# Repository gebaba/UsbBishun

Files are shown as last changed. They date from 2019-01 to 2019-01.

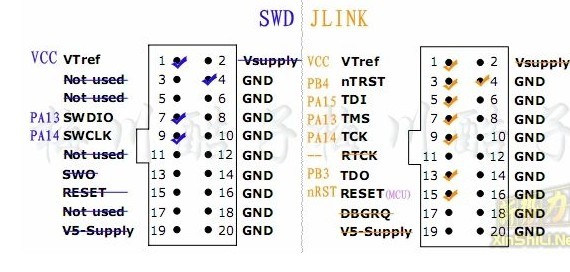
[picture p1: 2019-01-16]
Documents/DEBUG.jpg

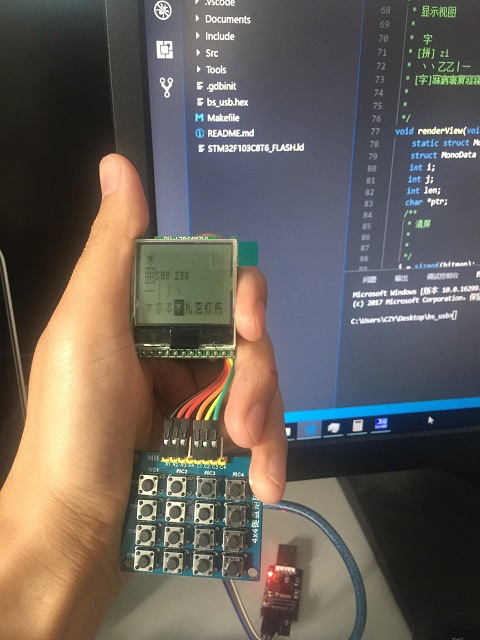
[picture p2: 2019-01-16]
20181016140855.jpg

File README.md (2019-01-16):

# 带笔画输入法的键盘

1 横/提<br />
2 竖/竖钩<br />
3 撇<br />
4 捺/点<br />
5 折<br />
6 回退/清除<br />
7 确定/模式<br />
8 上翻/放大<br />
9 下翻/缩小<br />



# 第一版问题

W26Q16 存储器和 STM32F103C8T6 的 SPI1 接口错误 PA6/PA7 颠倒<br />
复位按键封装过小<br />
USB 口 500mA 电阻封装过小<br />
按键和 LCD 的接口根据布线进行调整<br />
屏幕灯的封装过小<br />
32769 晶震处过孔<br />

外壳液晶屏位置调整<br />
外壳腔体高度过低需要留有一定余量<br />

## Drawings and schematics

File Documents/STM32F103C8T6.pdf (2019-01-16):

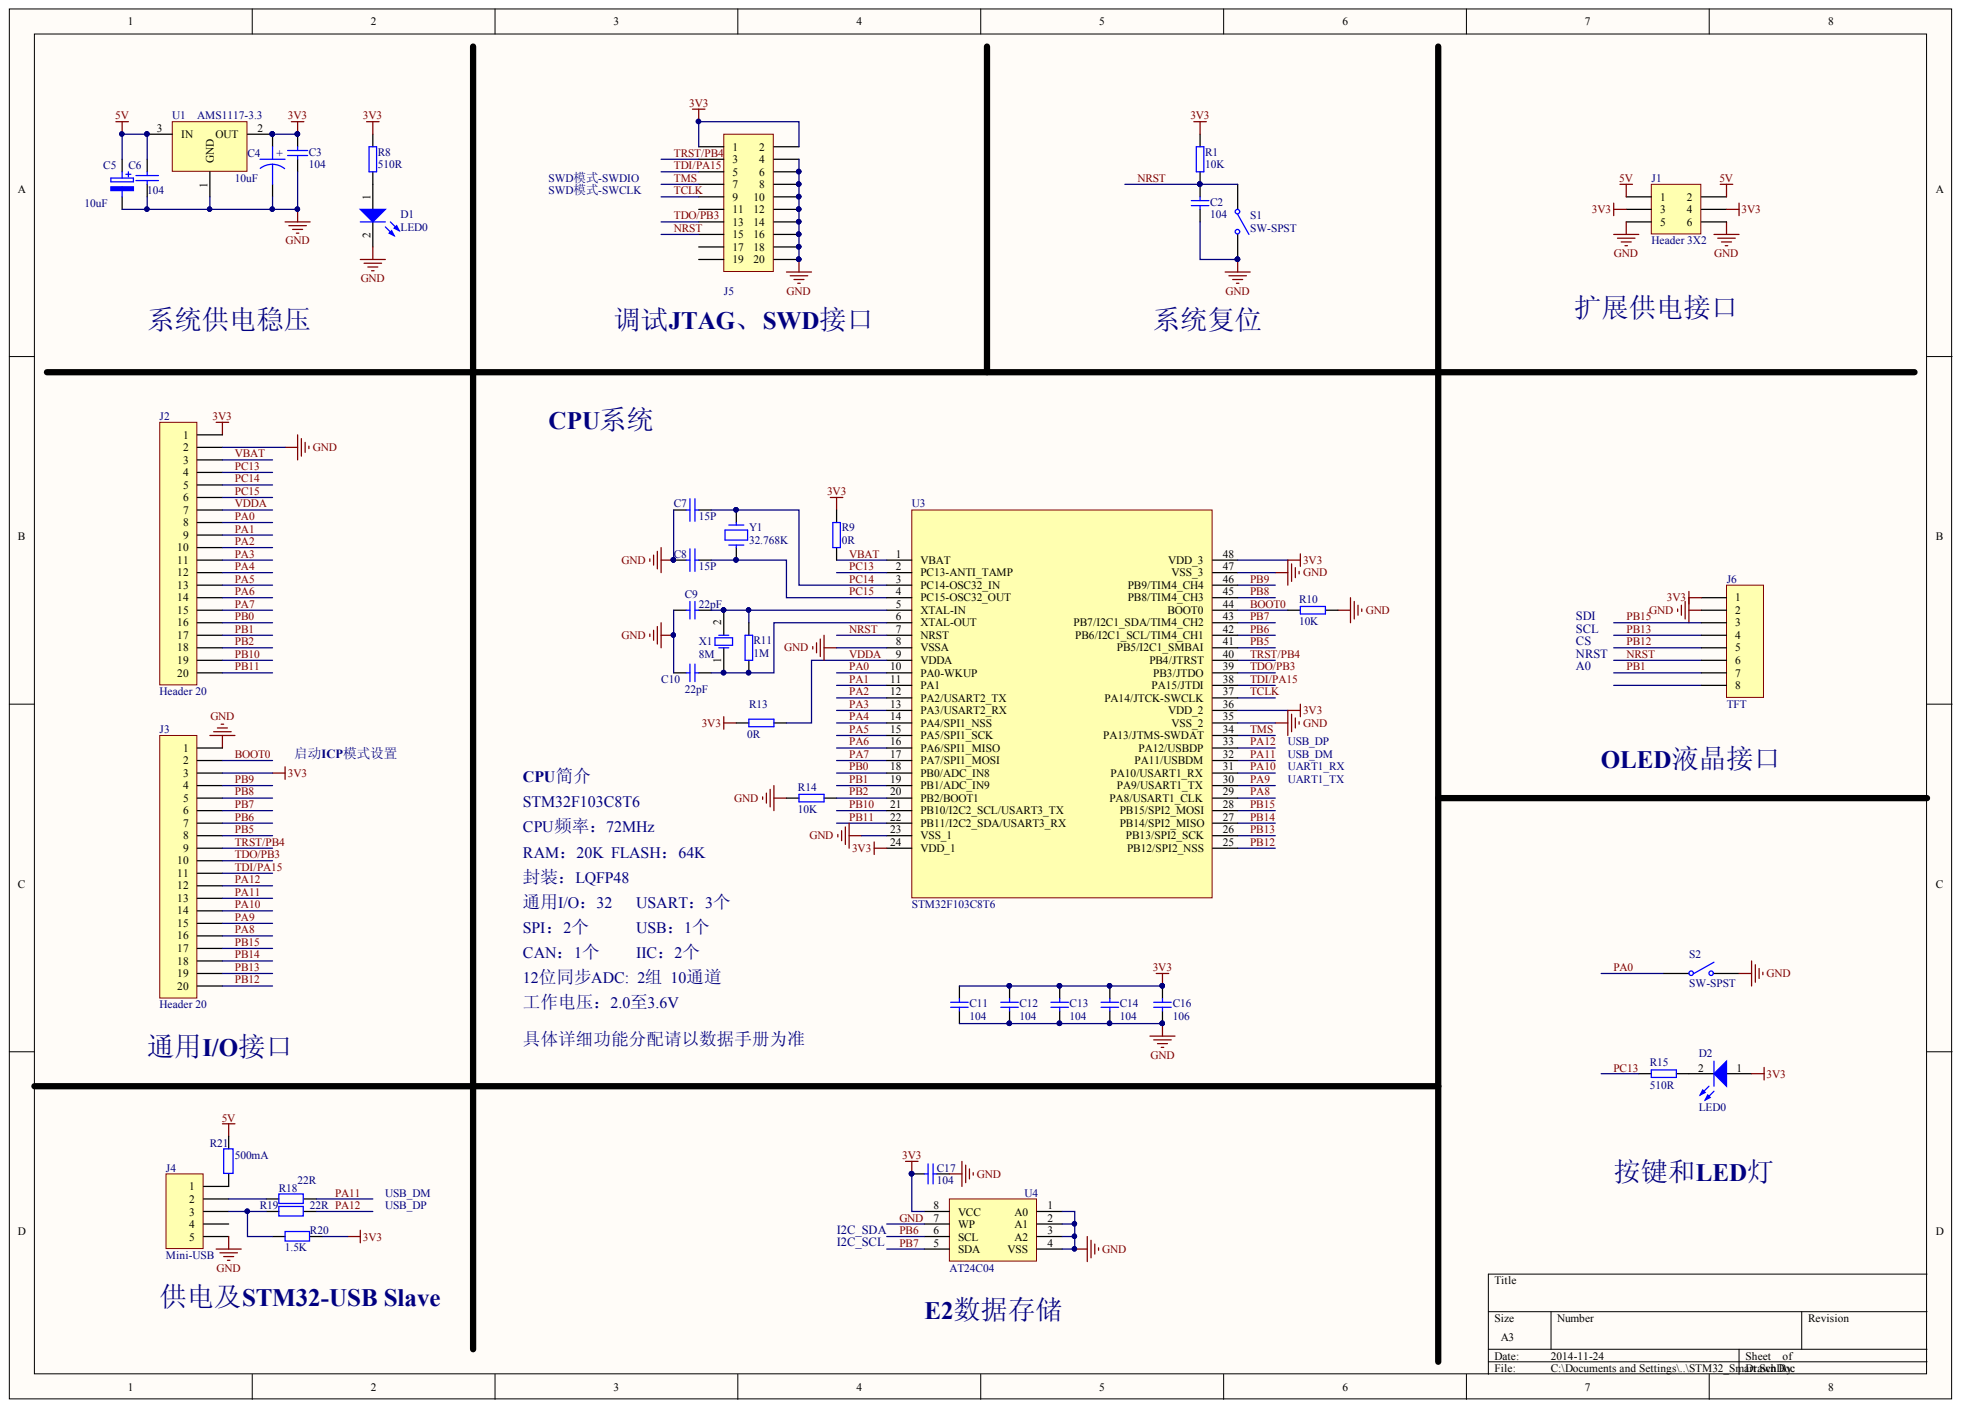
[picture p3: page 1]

tr.SchD awn Bocy:

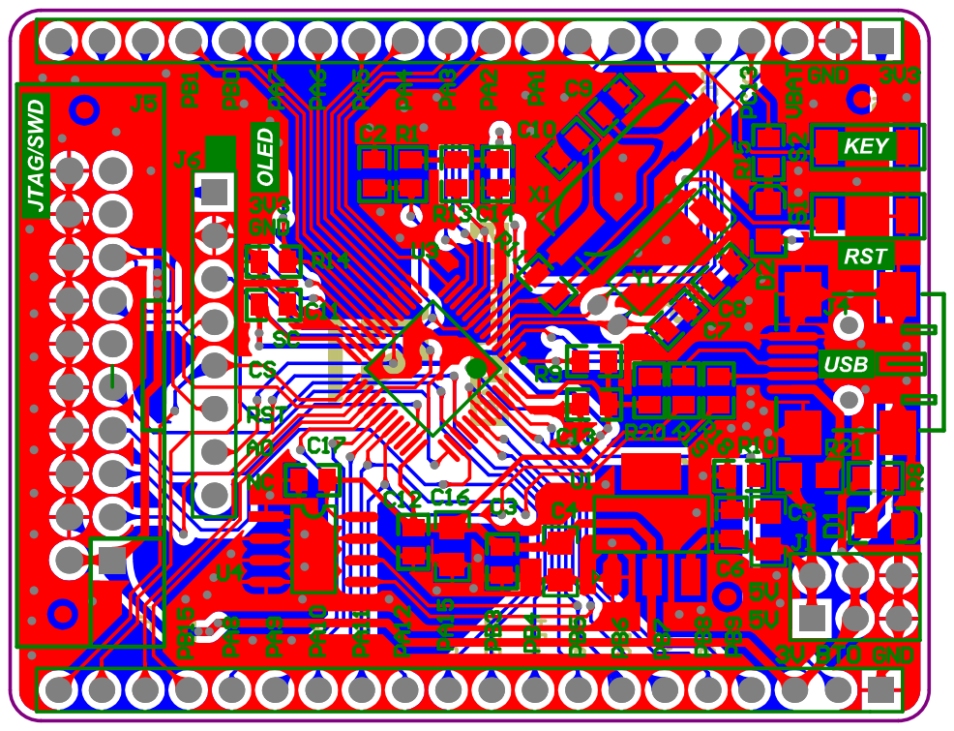
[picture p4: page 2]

Comment | Description | Designator | Footprint | LibRef | Quantity
104 | Capacitor | C2, C3, C6, C11, C12, C13, C14, C17 | RC0603 | CAP1, Cap, CAP, CAP1, CAP1, CAP1, CAP1, Cap | 8
10uF | Capacitor, [NoValue] | C4, C5 | RC0805 | CAPACITOR POL, ELECTRO2 | 2
15P | | C7, C8 | RC0603 | CAP | 2
22pF | Capacitor | C9, C10 | RC0603 | CAP1 | 2
106 | Capacitor | C16 | RC0805 | CAP1 | 1
LED0 | Typical INFRARED GaAs LED | D1, D2 | LED0805 | LED0 | 2
Header 3X2 | Header, 3-Pin, Dual row | J1 | IDE3X2-2.54 | Header 3X2 | 1
Header 20 | Header, 20-Pin | J2, J3 | HDR1X20 | Header 20 | 2
Mini-USB | Header, 5-Pin | J4 | mini_USB | Header 5 | 1
| Header, 10-Pin, Dual row, Right Angle | J5 | JTAG20P | Header 10X2H | 1
TFT | Header, 8-Pin | J6 | HDR1X8 | Header 8 | 1
10K | | R1, R10, R14 | RC0603 | R | 3
510R | | R8, R15 | RC0603 | R | 2
0R | | R9, R13 | RC0603 | R | 2
1M | | R11 | RC0603 | R | 1
22R | Resistor | R18, R19 | RC0603 | Res2 | 2
1.5K | Resistor | R20 | RC0603 | Res2 | 1
500mA | Resistor | R21 | RC0805 | Res2 | 1
SW-SPST | Single-Pole, Single-Throw Switch | S1, S2 | SMT-KEY | SW-SPST | 2
AMS1117-3.3 | | U1 | SOT223 | LT1085CM-3.3 | 1
STM32F103C8T6 | | U3 | LQFP48 | STM32F103C8T6 | 1
AT24C04 | | U4 | SOIC-8P | EPROM | 1
8M | Crystal Oscillator | X1 | SMD49S | XTAL_SMD | 1
32.768K | 晶振 | Y1 | JZ32768 | CRYSTAL | 1

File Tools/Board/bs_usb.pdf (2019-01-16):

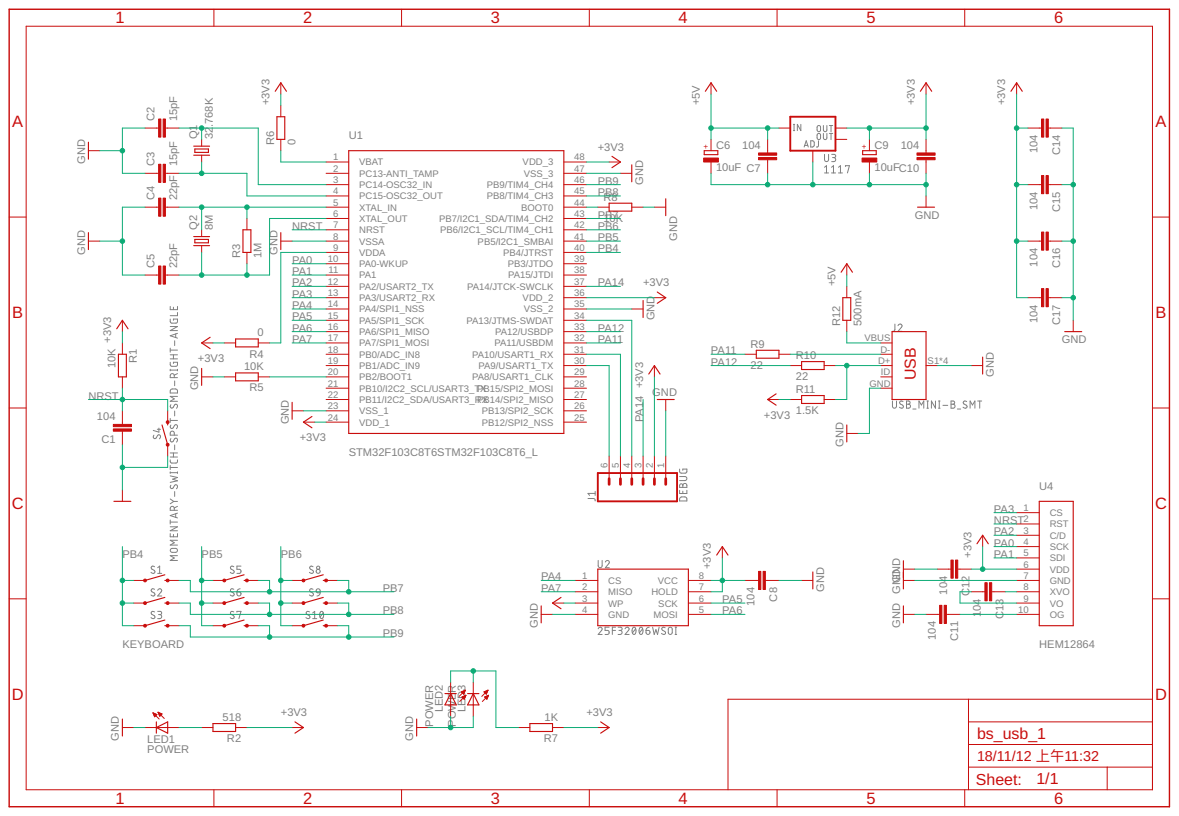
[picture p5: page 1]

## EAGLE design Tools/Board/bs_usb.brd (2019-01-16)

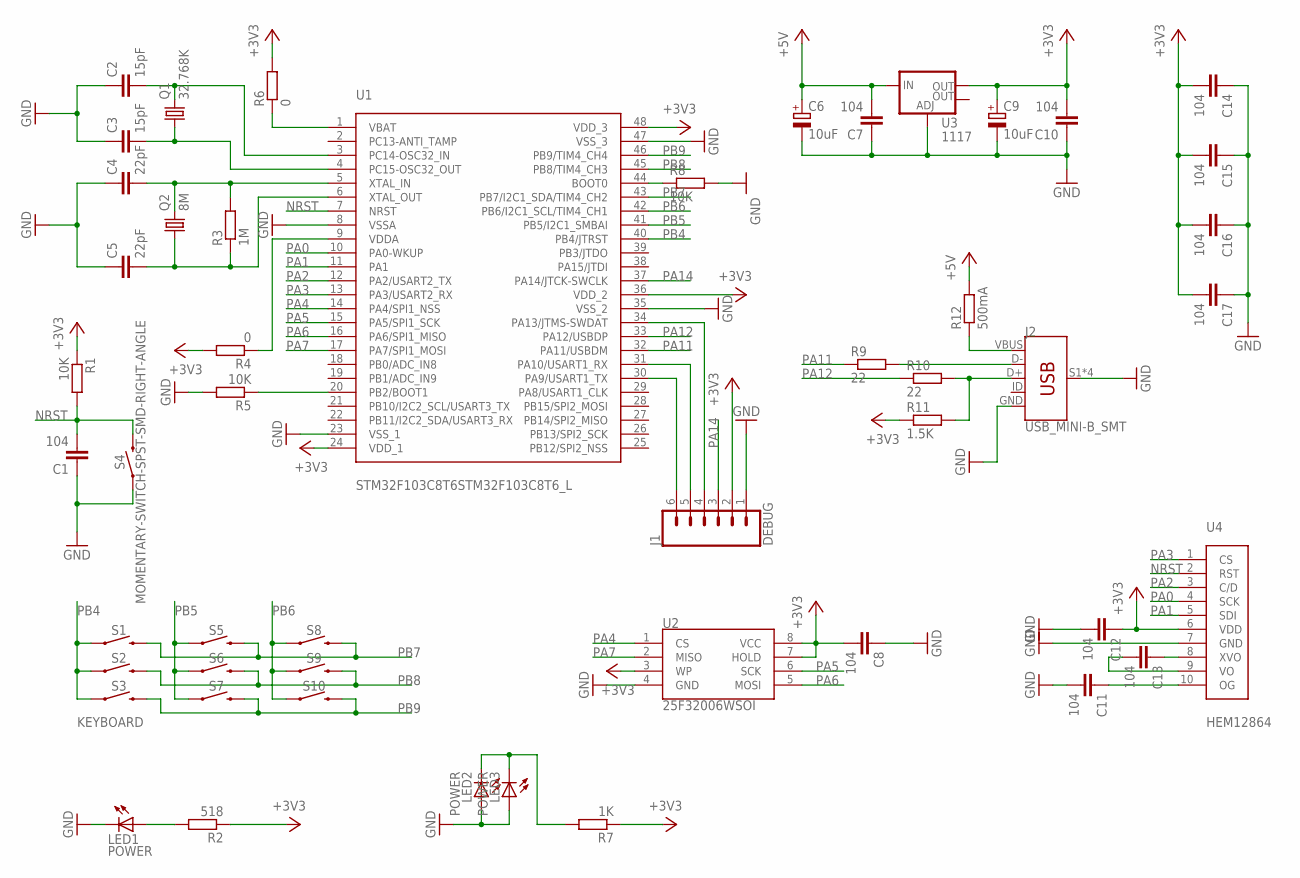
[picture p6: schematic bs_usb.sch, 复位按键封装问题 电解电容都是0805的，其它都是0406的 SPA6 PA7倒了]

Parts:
C1, C7, C8, C10, C11, C12, C13, C14, C15, C16, C17: 104; C0603
C2, C3: 15pF; C0603
C4, C5: 22pF; C0603
C6, C9: 10uF; A/3216-18R
J1: DEBUG; 1X06_NO_SILK
J2: USB_MINI-B_SMT; USB-MINIB
LED1, LED2, LED3: POWER; CHIP-LED0805
Q1: 32.768K; TC26H
Q2: 8M; SM49
R1, R5, R8: 10K; R0603
R2: 518; R0603
R3: 1M; R0603
R4, R6: 0; R0603
R7: 1K; R0603
R9, R10: 22; R0603
R11: 1.5K; R0603
R12: 500mA; R0603
S1, S2, S3, S5, S6, S7, S8, S9, S10: MOMENTARY-SWITCH-SPST-PTH-6.0MM; TACTILE_SWITCH_PTH_6.0MM
S4: MOMENTARY-SWITCH-SPST-SMD-RIGHT-ANGLE; TACTILE_SWITCH_SMD_RIGHT_ANGLE
U1: STM32F103C8T6STM32F103C8T6_L; TQFP48_7X7
U2: 25F32006WSOI; SO08-EIAJ
U3: 1117; SOT223
U4: HEM12864

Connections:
+3V3: C8.2, C9.+, C10.2, C12.1, C14.2, C15.2, C16.2, C17.2, J1.2, R1.1, R2.1, R4.2, R6.2, R7.1, R11.1, U1.24 (VDD_1), U1.36 (VDD_2), U1.48 (VDD_3), U2.3 (WP), U2.7 (HOLD), U2.8 (VCC), U3.2 (OUT), U4.6 (VDD)
+5V: C6.+, C7.2, R12.2, U3.3 (IN)
GND: C1.1, C2.1, C3.1, C4.1, C5.1, C6.-, C7.1, C8.1, C9.-, C10.1, C11.2, C12.2, C14.1, C15.1, C16.1, C17.1, J1.1, J2.GND, J2.S1 (SHIELD), J2.S2 (SHIELD), J2.S3 (SHIELD), J2.S4 (SHIELD), LED1.C, LED2.A, LED3.A, R5.2, R8.2, S4.1, U1.8 (VSSA), U1.23 (VSS_1), U1.35 (VSS_2), U1.47 (VSS_3), U2.4 (GND), U3.1 (ADJ), U4.7 (GND)
unnamed: R8.1, U1.44 (BOOT0)
unnamed: R6.1, U1.1 (VBAT)
unnamed: R5.1, U1.20 (PB2/BOOT1)
unnamed: R4.1, U1.9 (VDDA)
unnamed: C4.2, Q2.2, R3.2, U1.5 (XTAL_IN)
unnamed: C2.2, Q1.2, U1.3 (PC14-OSC32_IN)
unnamed: C5.2, Q2.1, R3.1, U1.6 (XTAL_OUT)
unnamed: C3.2, Q1.1, U1.4 (PC15-OSC32_OUT)
unnamed: J2.D-, R9.2
unnamed: J2.D+, R10.2, R11.2
unnamed: J2.VBUS, R12.1
unnamed: J1.6, U1.30 (PA9/USART1_TX)
unnamed: J1.5, U1.31 (PA10/USART1_RX)
unnamed: C13.1, U4.8 (XVO)
unnamed: C13.2, U4.9 (VO)
unnamed: C11.1, U4.10 (OG)
unnamed: LED2.C, LED3.C, R7.2
unnamed: LED1.A, R2.2
NRST: C1.2, R1.2, S4.2, U1.7 (NRST), U4.2 (RST)
PA0: U1.10 (PA0-WKUP), U4.4 (SCK)
PA1: U1.11 (PA1), U4.5 (SDI)
PA2: U1.12 (PA2/USART2_TX), U4.3 (C/D)
PA3: U1.13 (PA3/USART2_RX), U4.1 (CS)
PA4: U1.14 (PA4/SPI1_NSS), U2.1 (CS)
PA5: U1.15 (PA5/SPI1_SCK), U2.6 (SCK)
PA6: U1.16 (PA6/SPI1_MISO), U2.5 (MOSI)
PA7: U1.17 (PA7/SPI1_MOSI), U2.2 (MISO)
PA11: R9.1, U1.32 (PA11/USBDM)
PA12: R10.1, U1.33 (PA12/USBDP)
PA13: J1.4, U1.34 (PA13/JTMS-SWDAT)
PA14: J1.3, U1.37 (PA14/JTCK-SWCLK)
PB4: S1.1, S2.1, S3.1, U1.40 (PB4/JTRST)
PB5: S5.1, S6.1, S7.1, U1.41 (PB5/I2C1_SMBAI)
PB6: S8.1, S9.1, S10.1, U1.42 (PB6/I2C1_SCL/TIM4_CH1)
PB7: S1.3 (2), S5.3 (2), S8.3 (2), U1.43 (PB7/I2C1_SDA/TIM4_CH2)
PB8: S2.3 (2), S6.3 (2), S9.3 (2), U1.45 (PB8/TIM4_CH3)
PB9: S3.3 (2), S7.3 (2), S10.3 (2), U1.46 (PB9/TIM4_CH4)

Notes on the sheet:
KEYBOARD

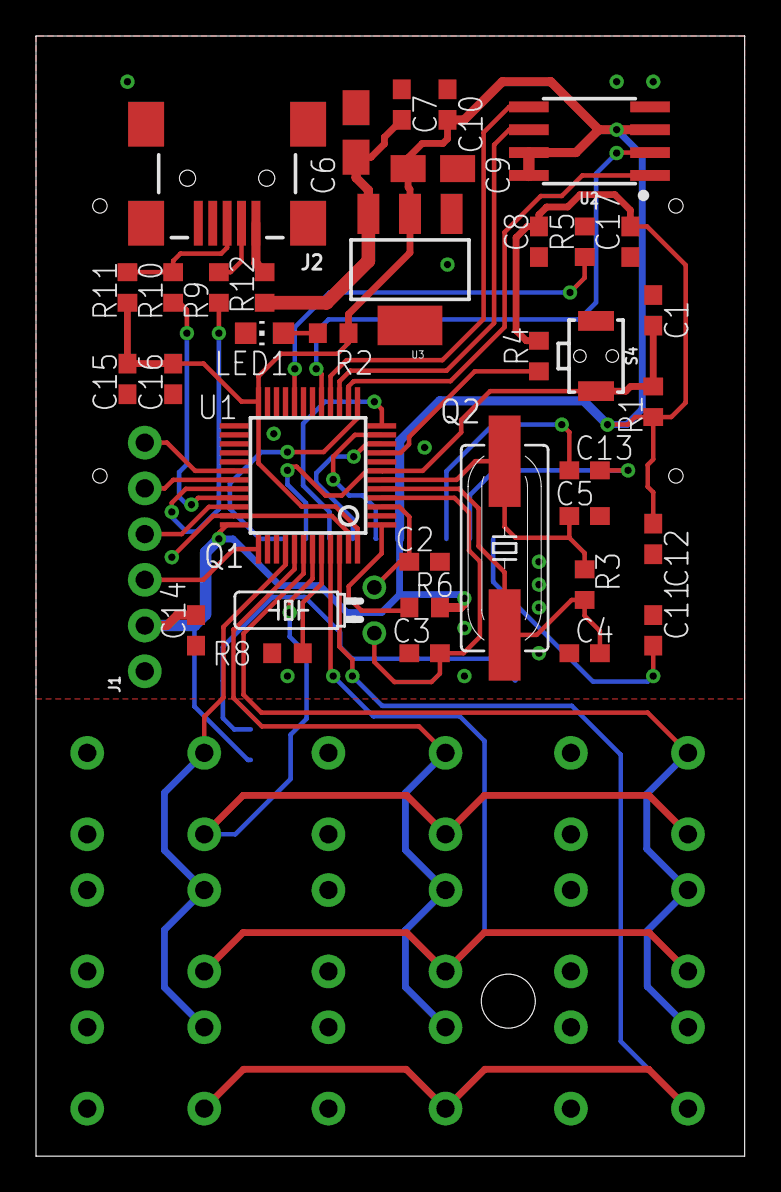
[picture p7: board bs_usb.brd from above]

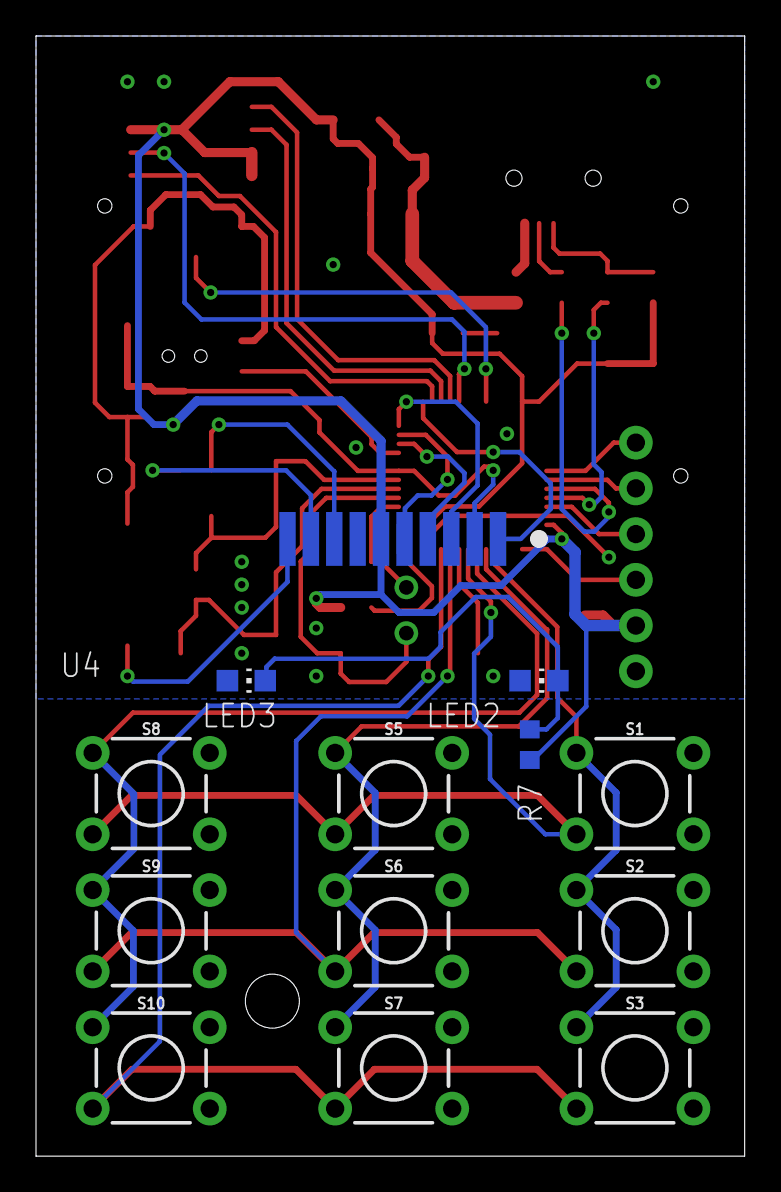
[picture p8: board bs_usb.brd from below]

Board: 2 copper layers, 39.4 x 62.2 mm, 50 parts (13 on the bottom side), 40 nets.

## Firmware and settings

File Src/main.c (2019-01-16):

/**
 * MVC 
 * stm32f103c8t6 对应 STM32F10X_MD
 * 
 * 
 */
#include "display.h"
#include "graph.h"
#include "ime.h"
#include "storage.h"
#include "keyboard.h"
#include "usb_keyboard.h"

#include "missing.h"

#include "stm32f10x_conf.h"

#define CANDIDATE_MAX 64

const char *ALPHABET[] = {
    "\x80\x00\x80\x00\x80\x00\x80\x00\x80\x00\x80\x00\x80\x00\x80\x00\x80\x00\x80\x00\x80\x00\x80\x00\x80\x00\x80\x00\x80\x00\x00\x00", //一
    "\x00\x00\x00\x00\x00\x00\x00\x00\x00\x00\x00\x00\x00\x00\xff\xff\x00\x00\x00\x00\x00\x00\x00\x00\x00\x00\x00\x00\x00\x00\x00\x00", //丨
    "\x00\x00\x00\x00\x00\x80\x00\x40\x00\x20\x00\x18\x00\x06\xff\x01\x00\x00\x00\x00\x00\x00\x00\x00\x00\x00\x00\x00\x00\x00\x00\x00", //丿
    "\x00\x00\x00\x00\x00\x00\x00\x00\x00\x00\x20\x00\x40\x00\x80\x00\x00\x01\x00\x06\x00\x00\x00\x00\x00\x00\x00\x00\x00\x00\x00\x00", //丶
    "\x00\x00\x02\x00\x02\x38\x02\x46\x02\x41\x82\x40\x42\x40\x22\x40\x12\x40\x0a\x40\x06\x40\x02\x40\x00\x40\x00\x78\x00\x00\x00\x00", //乙
    "\xff\xff\x01\x80\x21\x82\x21\xa2\xfd\xbf\x21\x81\x01\x82\x25\xa2\xe9\x9f\x21\x82\x21\x82\xe9\xbf\x25\x82\x01\x80\x01\x80\xff\xff", //拼
    "\xff\xff\x01\x80\x09\xa0\x89\xa0\x89\xb8\x89\xa7\xf9\xa0\x89\xa0\x89\xa0\x89\xa0\x89\xbf\x09\xa0\x01\xa0\x01\x80\x01\x80\xff\xff", //五
    "\x00\x00\x00\x08\x80\x0f\x70\x02\xc0\x03\x00\x0e\x00\x08\x00\x00", // a
    "\x00\x00\x10\x08\xf0\x0f\x90\x08\x90\x08\x60\x07\x00\x00\x00\x00", // b
    "\x00\x00\xe0\x07\x10\x08\x10\x08\x10\x08\x30\x04\x00\x00\x00\x00", // c
    "\x00\x00\x10\x08\xf0\x0f\x10\x08\x10\x08\xe0\x07\x00\x00\x00\x00", // d
    "\x00\x00\x10\x08\xf0\x0f\x90\x08\xd0\x09\x30\x0c\x00\x00\x00\x00", // e
    "\x00\x00\x10\x08\xf0\x0f\x90\x08\xd0\x01\x30\x00\x00\x00\x00\x00", // f
    "\x00\x00\xc0\x03\x20\x04\x10\x08\x10\x09\x30\x07\x00\x01\x00\x00", // g
    "\x00\x00\x10\x08\xf0\x0f\x80\x00\x80\x00\xf0\x0f\x10\x08\x00\x00", // h
    "\x00\x00\x10\x08\x10\x08\xf0\x0f\x10\x08\x10\x08\x00\x00\x00\x00", // i
    "\x00\x00\x00\x30\x10\x20\x10\x20\xf0\x1f\x10\x00\x10\x00\x00\x00", // j
    "\x00\x00\x10\x08\xf0\x0f\x90\x08\x40\x01\x30\x0e\x10\x08\x00\x00", // k
    "\x00\x00\x10\x08\xf0\x0f\x10\x08\x00\x08\x00\x08\x00\x0c\x00\x00", // l
    "\x10\x08\xf0\x0f\xf0\x00\x00\x0f\xf0\x00\xf0\x0f\x10\x08\x00\x00", // m
    "\x00\x00\x10\x08\xf0\x0f\xc0\x08\x10\x03\xf0\x0f\x10\x00\x00\x00", // n
    "\x00\x00\xe0\x07\x10\x08\x10\x08\x10\x08\xe0\x07\x00\x00\x00\x00", // o
    "\x00\x00\x10\x08\xf0\x0f\x90\x08\x90\x00\x60\x00\x00\x00\x00\x00", // p
    "\x00\x00\xe0\x07\x10\x0a\x10\x0a\x10\x1c\xe0\x17\x00\x00\x00\x00", // q
    "\x00\x00\x10\x08\xf0\x0f\x90\x08\x90\x01\x60\x0e\x00\x08\x00\x00", // r
    "\x00\x00\x60\x0c\x90\x08\x90\x08\x10\x09\x30\x06\x00\x00\x00\x00", // s
    "\x00\x00\x30\x00\x10\x08\xf0\x0f\x10\x08\x30\x00\x00\x00\x00\x00", // t
    "\x00\x00\x10\x00\xf0\x07\x00\x08\x00\x08\xf0\x07\x10\x00\x00\x00", // u
    "\x00\x00\x10\x00\xf0\x01\x00\x0e\x80\x03\x70\x00\x10\x00\x00\x00", // v
    "\x00\x00\xf0\x00\x00\x0f\xf0\x01\x00\x0f\xf0\x00\x00\x00\x00\x00", // w
    "\x00\x00\x10\x08\x70\x0e\x80\x01\x70\x0e\x10\x08\x00\x00\x00\x00", // x
    "\x00\x00\x10\x00\xf0\x08\x00\x0f\xf0\x08\x10\x00\x00\x00\x00\x00", // y
    "\x00\x00\x30\x08\x10\x0e\x90\x09\x70\x08\x10\x0c\x00\x00\x00\x00"  // z
};

char mode;
char input[BH_MAX + 1];

void *handle;
struct Data candidate[CANDIDATE_MAX];
int candidateSize;
int start;
int current;

char bitmap[ROW_MAX * COL_MAX];

/**
 * 显示视图
 * 
 *  字
 * [拼] zi
 *  丶丶乙乙丨一
 * [字]寐寎寤賔寣寢寱
 * 
 * 
 */
void renderView(void) {
    static struct MonoData d = {ROW_MAX * 8, COL_MAX, bitmap};
    struct MonoData monoData = {16};
    int i;
    int j;
    int len;
    char *ptr;
    /**
     * 清屏
     * 
     * 
     */
    i = sizeof(bitmap);
    while (i--) {
        bitmap[i] = 0;
    }
    if (candidateSize) {
        monoData.h = 16;
        monoData.bitmap = candidate[current].bitmap;
        copyImage(&d, 0, 0, monoData, 0);
        monoData.bitmap = (char *) ALPHABET[!mode ? 5 : 6];
        copyImage(&d, 16, 0, monoData, 0);
        ptr = !mode ? candidate[current].pinyin : candidate[current].wubi;
        monoData.h = 8;
        for (int i = 0; i < strlen(ptr); i++) {
            if ('a' <= ptr[i] && ptr[i] <= 'z') {
                monoData.bitmap = (char *) ALPHABET[7 + ptr[i] - 'a'];
                copyImage(&d, 16, 16 + i * 8, monoData, 0);
            }
        }
    }
    monoData.h = 16;
    for (i = 0, j = (len = strlen(input)) > 8 ? len - 8 : 0; j < len; i++, j++) {
        monoData.bitmap = (char *) ALPHABET[input[j] - 1];
        copyImage(&d, 32, i * 16, monoData, 0);
    }
    for (i = 0, j = start; i < 8 && j < candidateSize; i++, j++) {
        monoData.bitmap = candidate[j].bitmap;
        copyImage(&d, 48, i * 16, monoData, j == current);
    }
}

/**
 * 重新搜索
 * 
 * 
 */
void onInputChange(void) {
    int i;
    if (handle) {
        freeSearch(handle);
    }
    if (strlen(input) && (handle = createSearch(input))) {
        for (i = 0; i < 8; i++) {
            if (!search(handle, &candidate[i])) {
                break;
            }
        }
        candidateSize = i;
    } else {
        candidateSize = 0;
    }
    start = 0;
    current = 0;
}

/**
 * 执行按键动作
 * 
 * key: 按键 
 * 
 * 
 */
void doKey(char key) {
    switch (key) {
    case KEY_H:
    case KEY_S:
    case KEY_P:
    case KEY_N:
    case KEY_Z:
        {
            int len = strlen(input);
            if (len < BH_MAX) {
                input[len++] = key + 1, input[len] = 0;
                onInputChange();
            }
        }
        break;
    case KEY_OK:
        if (current < candidateSize) {
            int i;
            char *key = !mode ? candidate[current].pinyin : candidate[current].wubi;
            for (i = 0; i < strlen(key) && key[i] != '|'; i++) {
                sendKey(key[i]);
            }
            input[0] = 0;
            onInputChange();
        }
        break;
    case KEY_MODE:
        mode = !mode;
        break;
    case KEY_DELETE:
        {
            int len = strlen(input);
            if (len) {
                input[--len] = 0;
                onInputChange();
            }
        }
        break;
    case KEY_CLEAR:
        /**
         * 清除
         * 
         * 
         */
        input[0] = 0;
        onInputChange();
        break;
    case KEY_PREVIOUS:
        if (current) {
            current--;
            if (start > current) {
                start--;
            }
        }
        break;
    case KEY_NEXT:
        if (current < candidateSize && candidateSize < CANDIDATE_MAX) {
            current++;
            if (current == candidateSize) {
                if (search(handle, &candidate[current])) {
                    candidateSize++;
                } else {
                    current--;
                }
            }
            if (start + 8 <= current) {
                start++;
            }
        }
        break;
    case KEY_ZOOM:
        sendKey('+');
        break;
    case KEY_ZOOMOUT:
        sendKey('-');
        break;
    }
}

#ifdef INITIALIZE_STORAGE

#define PAGESIZE 256
#define SECTORSIZE 4096
#define BAUD 115200

/**
 * 通过串口数据初始化存储器
 * 
 * 
 */
int main(int argc, char *argv[]) {
    char buf[SECTORSIZE];
    int start = 0;
    RCC_APB2PeriphClockCmd(RCC_APB2Periph_GPIOA, ENABLE);
    RCC_APB2PeriphClockCmd(RCC_APB2Periph_USART1, ENABLE);
    RCC_APB2PeriphClockCmd(RCC_APB2Periph_AFIO, ENABLE);
    {
        GPIO_InitTypeDef GPIO_InitStruct;
        GPIO_InitStruct.GPIO_Pin = GPIO_Pin_9;
        GPIO_InitStruct.GPIO_Mode = GPIO_Mode_AF_PP;
        GPIO_InitStruct.GPIO_Speed = GPIO_Speed_50MHz;
        GPIO_Init(GPIOA, &GPIO_InitStruct);
        GPIO_InitStruct.GPIO_Pin = GPIO_Pin_10;
        GPIO_InitStruct.GPIO_Mode = GPIO_Mode_IN_FLOATING;
        GPIO_Init(GPIOA, &GPIO_InitStruct);
    }
    {
        USART_InitTypeDef USART_InitStruct;
        USART_InitStruct.USART_BaudRate = BAUD;
        USART_InitStruct.USART_WordLength = USART_WordLength_8b;
        USART_InitStruct.USART_StopBits = USART_StopBits_1;
        USART_InitStruct.USART_Parity = USART_Parity_No ;
        USART_InitStruct.USART_HardwareFlowControl = USART_HardwareFlowControl_None;
        USART_InitStruct.USART_Mode = USART_Mode_Rx | USART_Mode_Tx;
        USART_Init(USART1, &USART_InitStruct);
    }
    USART_Cmd(USART1, ENABLE);
    initializeSpi();
    while (1) {
        int i;
        for (i = 0; i < SECTORSIZE;) {
            if (USART_GetFlagStatus(USART1, USART_FLAG_RXNE) != RESET) {
                buf[i++] = USART_ReceiveData(USART1);
            }
        }
        erase(start);
        for (i = 0; i < SECTORSIZE; i += PAGESIZE) {
            sendData(&buf[i], PAGESIZE, start + i);
        }
        start += SECTORSIZE;
        USART_SendData(USART1, 0xff);
    } 
    return 0;
}

#else
/**
 * 主程序
 * 
 * 
 */
int main(int argc, char *argv[]) {
    SysTick_CLKSourceConfig(SysTick_CLKSource_HCLK_Div8);
    initializeSpi();
    initializeLcd();
    initializeKey();
    // initializeUsb();
    while (1) {
        doKey(readKey());
        renderView();
        draw(bitmap);
    }
}

#endif

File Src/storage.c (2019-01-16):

/**
 * 引脚 PA4 PA5 PA6 PA7[SPI1]
 * 
 * 
 */
#include "storage.h"

#include "stm32f10x_conf.h"

#define	SEL_SET GPIO_SetBits(GPIOA, GPIO_Pin_4)
#define	SEL_CLR GPIO_ResetBits(GPIOA, GPIO_Pin_4)

#ifndef USE_SPI1

#define	SCK_SET GPIO_SetBits(GPIOA, GPIO_Pin_5)
#define	SCK_CLR GPIO_ResetBits(GPIOA, GPIO_Pin_5)
#define	SDO_SET GPIO_SetBits(GPIOA, GPIO_Pin_6)
#define	SDO_CLR GPIO_ResetBits(GPIOA, GPIO_Pin_6)
#define	SDI_GET GPIO_ReadInputDataBit(GPIOA, GPIO_Pin_7)

#endif

/**
 * 发送或者接收数据
 * 
 * data: DUMMY-0xA5 要发送的数据
 * 
 * return: 接收到的数据
 * 
 */
static char send(char data) {
#ifndef USE_SPI1
    int r = 0;
    int i;
    for (i = 0; i < 8; i++) {
        SCK_CLR;
        if (data & 0x80) {
            SDO_SET;
        } else {
            SDO_CLR;
        }
        data <<= 1;
        SCK_SET;
        r <<= 1;
        if (SDI_GET) {
            r |= 1;
        }
        SCK_CLR;
    }
    return r;
#else
    while (SPI_I2S_GetFlagStatus(
        SPI1,
        SPI_I2S_FLAG_TXE
    ) == RESET);
    SPI_I2S_SendData(SPI1, data);
    while (SPI_I2S_GetFlagStatus(SPI1, SPI_I2S_FLAG_RXNE) == RESET);
    return SPI_I2S_ReceiveData(SPI1);
#endif
}

/**
 * 初始化
 * 
 * return: JEDEC ID 
 * 
 */
int initializeSpi(void) {
    int id;
    RCC_APB2PeriphClockCmd(
        RCC_APB2Periph_GPIOA,
        ENABLE
    );
#ifndef USE_SPI1
    {
        GPIO_InitTypeDef GPIO_InitStruct;
        GPIO_InitStruct.GPIO_Pin = GPIO_Pin_4 | GPIO_Pin_5 | GPIO_Pin_6;
        GPIO_InitStruct.GPIO_Speed = GPIO_Speed_50MHz;
        GPIO_InitStruct.GPIO_Mode = GPIO_Mode_Out_PP;
        GPIO_Init(GPIOA, &GPIO_InitStruct);
        GPIO_InitStruct.GPIO_Pin = GPIO_Pin_7;
        GPIO_InitStruct.GPIO_Mode = GPIO_Mode_IPU;
        GPIO_Init(GPIOA, &GPIO_InitStruct);
    }
#else
    RCC_APB2PeriphClockCmd(RCC_APB2Periph_SPI1, ENABLE);
    RCC_APB2PeriphClockCmd(RCC_APB2Periph_AFIO, ENABLE);
    {
        GPIO_InitTypeDef GPIO_InitStruct;
        GPIO_InitStruct.GPIO_Pin = GPIO_Pin_5 | GPIO_Pin_6 | GPIO_Pin_7;
        GPIO_InitStruct.GPIO_Speed = GPIO_Speed_50MHz;
        GPIO_InitStruct.GPIO_Mode = GPIO_Mode_AF_PP;
        GPIO_Init(GPIOA, &GPIO_InitStruct);
        GPIO_InitStruct.GPIO_Pin = GPIO_Pin_4;
        GPIO_InitStruct.GPIO_Mode = GPIO_Mode_Out_PP;
        GPIO_Init(GPIOA, &GPIO_InitStruct);
    }
    {
        SPI_InitTypeDef SPI_InitStruct;
        SPI_InitStruct.SPI_Direction = SPI_Direction_2Lines_FullDuplex;
        SPI_InitStruct.SPI_Mode = SPI_Mode_Master;
        SPI_InitStruct.SPI_DataSize = SPI_DataSize_8b;
        SPI_InitStruct.SPI_CPOL = SPI_CPOL_High;
        SPI_InitStruct.SPI_CPHA = SPI_CPHA_2Edge;
        SPI_InitStruct.SPI_NSS = SPI_NSS_Soft;
        SPI_InitStruct.SPI_BaudRatePrescaler = SPI_BaudRatePrescaler_32;
        SPI_InitStruct.SPI_FirstBit = SPI_FirstBit_MSB;
        SPI_InitStruct.SPI_CRCPolynomial = 7;
        SPI_Init(SPI1, &SPI_InitStruct);
        SPI_Cmd(SPI1, ENABLE);
    }
#endif
    SEL_SET;
    SEL_CLR;
    send(0x9f);
    id = (send(0xff) << 16) | (send(0xff) << 8) | (send(0xff));
    SEL_SET;
    return id;
}

/**
 * 读数据
 * 
 * buf: 数据缓冲区
 * bufSize: 缓冲区大小
 * startAddress: 起始地址
 * 
 * return: 读到的数量
 * 
 */
int receiveData(char *buf, int bufSize, int startAddress) {
    int i;
    SEL_CLR;
    send(0x03);
    send((startAddress & 0xff0000) >> 16);
    send((startAddress & 0xff00) >> 8);
    send((startAddress & 0xff));
    for (i =  0; i < bufSize; i++) {
        buf[i] = send(0xff);
    }
    SEL_SET;
    return bufSize;
}

/**
 * 写数据
 * 
 * buf: 数据缓冲区
 * bufSize: 缓冲区大小
 * startAddress: 起始地址
 * 
 * return: 写入的数量
 * 
 */
int sendData(char *buf, int bufSize, int startAddress) {
    int i;
    SEL_CLR;
    send(0x06);
    SEL_SET;
    /**
     * 写使能
     * 
     * 
     */
    SEL_CLR;
    send(0x02);
    send((startAddress & 0xFF0000) >> 16);
    send((startAddress & 0xFF00) >> 8);  
    send((startAddress & 0xFF));
    for (i =  0; i < bufSize; i++) {
        send(buf[i]);
    }
    SEL_SET;
    /**
     * 等待写结束
     * 
     * 
     */
    SEL_CLR;
    send(0x05);
    while (send(0xff) & 0x01);
    SEL_SET;
    return bufSize;
}


/**
 * 块擦除
 * 
 * startAddress: 起始地址
 * 
 * return: 擦除大小
 * 
 */
int erase(int startAddress) {
    SEL_CLR;
    send(0x06);
    SEL_SET;
    SEL_CLR;
    send(0x01);
    send(0x00);
    send(0x00);
    SEL_SET;
    SEL_CLR;
    send(0x05);
    while (send(0xff) & 0x01);
    SEL_SET;
    /**
     * 擦除之前要清除写保护状态
     * 
     * 
     */
    SEL_CLR;
    send(0x06);
    SEL_SET;
    SEL_CLR;
    send(0x20);
    send((startAddress & 0xFF0000) >> 16);
    send((startAddress & 0xFF00) >> 8);  
    send((startAddress & 0xFF));
    SEL_SET;

    SEL_CLR;
    send(0x05);
    while (send(0xff) & 0x01);
    SEL_SET;
    return 4096;
}

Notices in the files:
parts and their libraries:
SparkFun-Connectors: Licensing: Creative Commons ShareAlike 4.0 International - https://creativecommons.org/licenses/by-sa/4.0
